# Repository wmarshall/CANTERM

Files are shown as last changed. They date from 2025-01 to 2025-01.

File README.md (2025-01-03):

# CANTERM

A single SKU for FRC teams providing the following features:

1. Fixed mounting junction for CAN connections, compatible with the 0.1" pitch connector of your choice (Molex SL footprints on silkscreen)
2. Solder pads and test points for 22AWG wire
3. 3 connection points - create short stubs out to individual devices and have a passthrough
4. Switchable termination - every junction can be a termination point!
5. Mountable to standard 0.5"x#10 FRC pitch grid

## Images

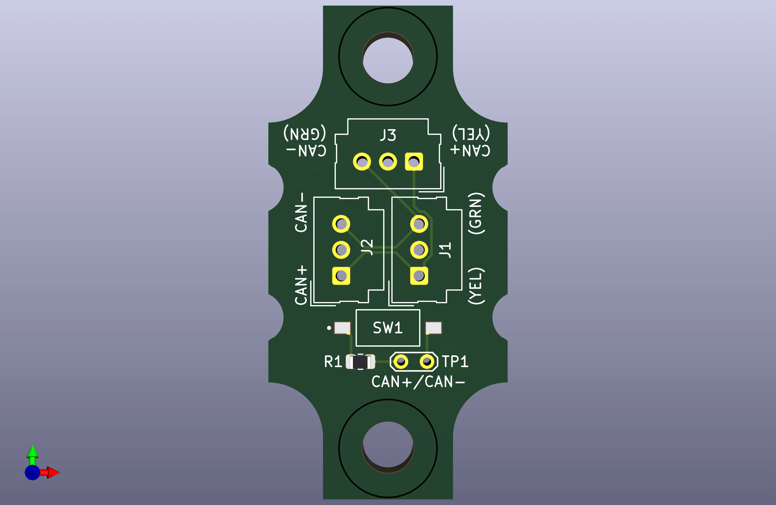
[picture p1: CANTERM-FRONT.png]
FRONT

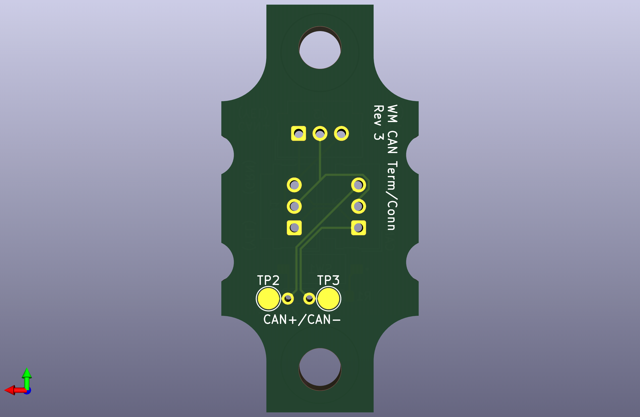
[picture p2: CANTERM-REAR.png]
REAR


Apologies for the flux slime + sharpied out silkscreen where I labeled things backwards in rev 1.

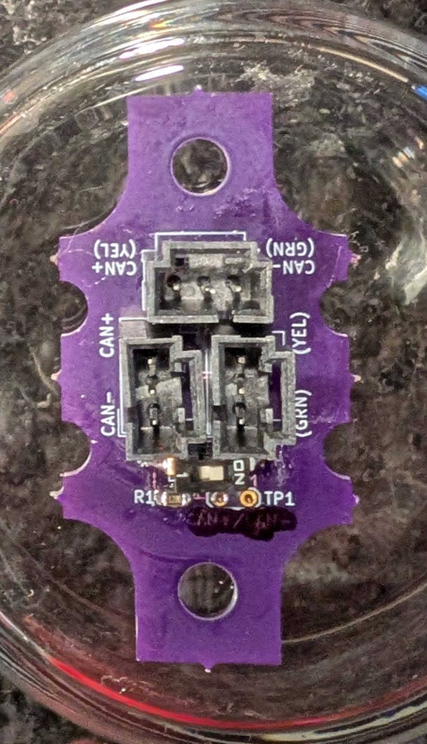
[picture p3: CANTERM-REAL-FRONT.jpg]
FRONT

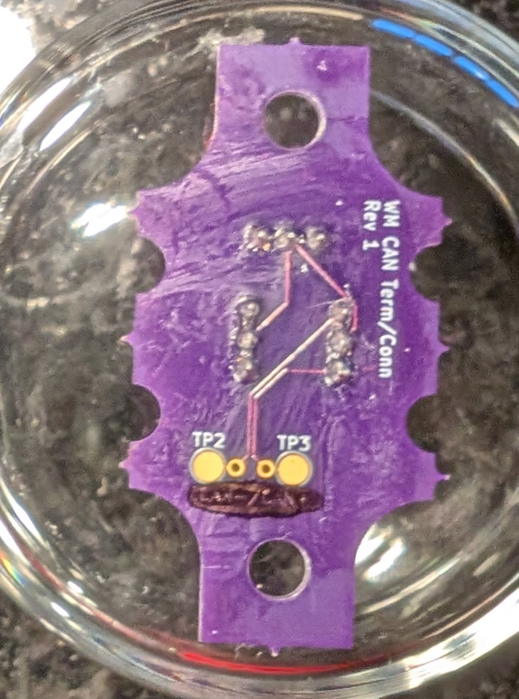
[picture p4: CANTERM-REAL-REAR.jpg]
REAR

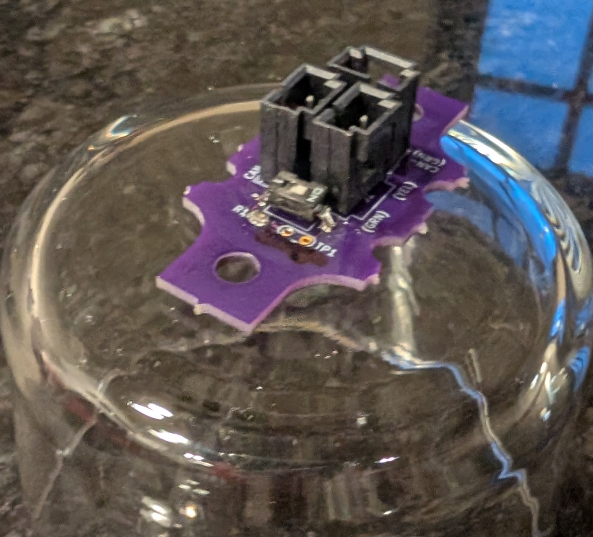
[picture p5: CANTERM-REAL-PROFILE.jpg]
PROFILE


## How to use

### Mounting

I recommend a fixed connection to a hard surface, with padding behind to prevent the through-hole pins from making electrical contact.

[Here](https://cad.onshape.com/documents/4bac7b549ef6666940699ce5/w/56cf0a0da1905853099fed6a/e/bae3fd6128463807bfcfc51d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) is a WIP Case CAD that accomplishes this.

### As a junction

1. Connect your input connector to one set of contacts
2. Connect your output connector to a second set of contacts
3. Set the termination switch to `OFF` (away from `ON`)

#### Debugging

Have a break in your CAN chain but don't know where it is? Use the switchable termination feature to find out where

1. Disconnect your output connector
2. Set the termination switch to `ON`
3. You should now have a properly terminated network on the input side. If problems persist, the break is on that side. If they don't the break is on the output side.
4. Repeatedly bisect the network until the problem is found
5. Reconnect connectors and set the termination back to `OFF`

### As a terminator

1. Connect your input connector to one set of contacts
3. Set the termination switch to `ON`

### As a junction with a stub

1. Connect your input connector to one set of contacts
2. Connect your output connector to a second set of contacts
3. Connect your stub connector to the third set of contacts
3. Set the termination switch to `OFF` (away from `ON`)

### As a terminator (soldered)

1. Strip ~3/8" of each of your CAN wires.
2. Feed them through the test points
3. Solder to the contact patches on the back, making sure to also solder through the test points
4. Trim excess wire.
5. Set the termination switch to `ON`

## BOM

1. 3x `Molex_SL_171971-0003` (only 2 needed if not making stubs)
2. 1x 120 ohm 0805 SMT resistor
3. 1x SPST 0.1" pitch SMT DIP switch (DS04-254-2-01BK-SMT is what I used)

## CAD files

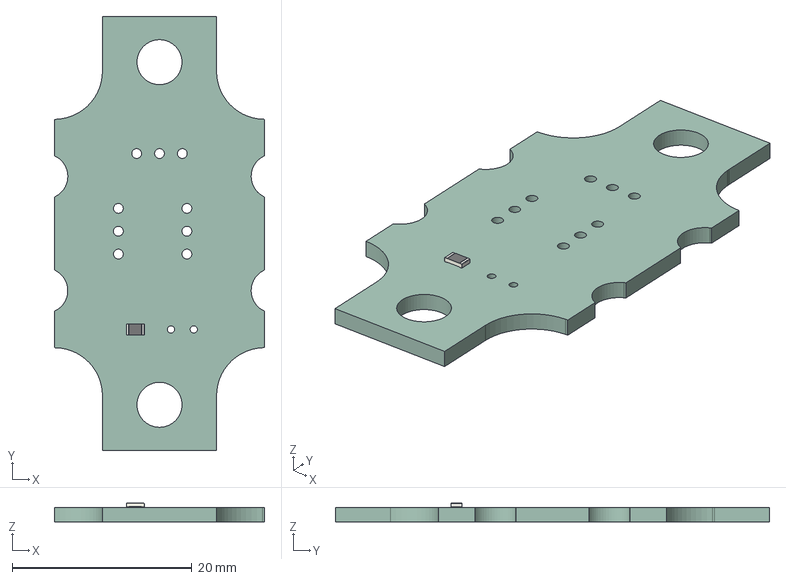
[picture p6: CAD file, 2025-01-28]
CANTERM.step
23.4 x 48.3 x 2.10 mm
R_0805_2012Metric
CANTERM_PCB

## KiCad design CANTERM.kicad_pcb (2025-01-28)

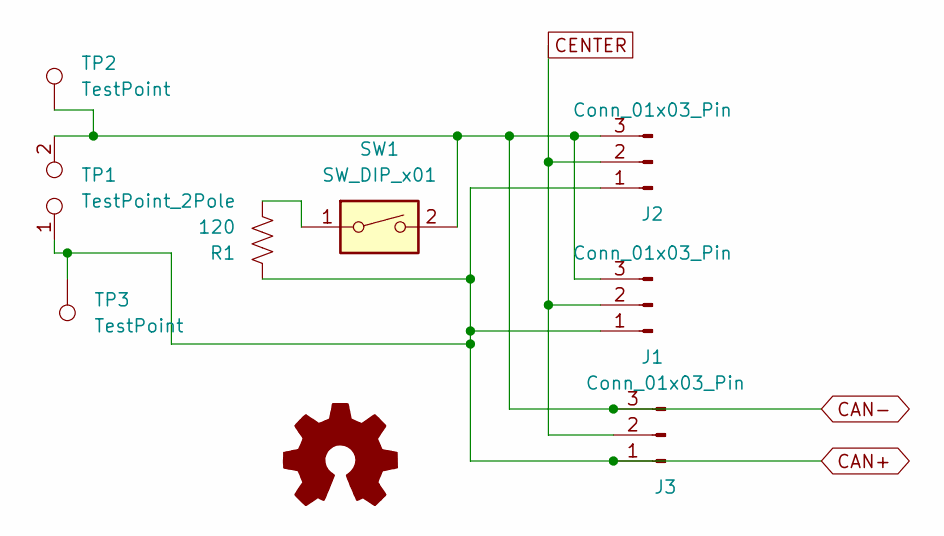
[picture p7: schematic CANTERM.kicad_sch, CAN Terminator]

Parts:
J1, J2, J3: Conn_01x03_Pin; Molex_SL_171971-0003_1x03_P2.54mm_Vertical
R1: 120; R_0805_2012Metric
SW1: SW_DIP_x01; SW_DS04-254-2-01BK-SMT
TP1: TestPoint_2Pole; TestPoint_2Pads_Pitch2.54mm_Drill0.8mm
TP2, TP3: TestPoint; TestPoint_Pad_D2.5mm

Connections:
CAN+: J1.1, J2.1, J3.1, R1.1, TP1.1, TP3.1
CAN-: J1.3, J2.3, J3.3, SW1.2, TP1.2, TP2.1
CENTER: J1.2, J2.2, J3.2
unnamed: R1.2, SW1.1

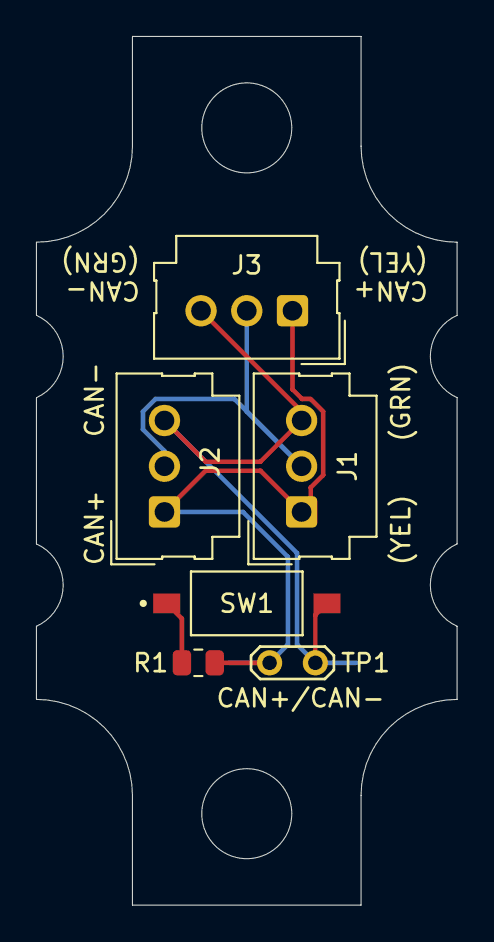
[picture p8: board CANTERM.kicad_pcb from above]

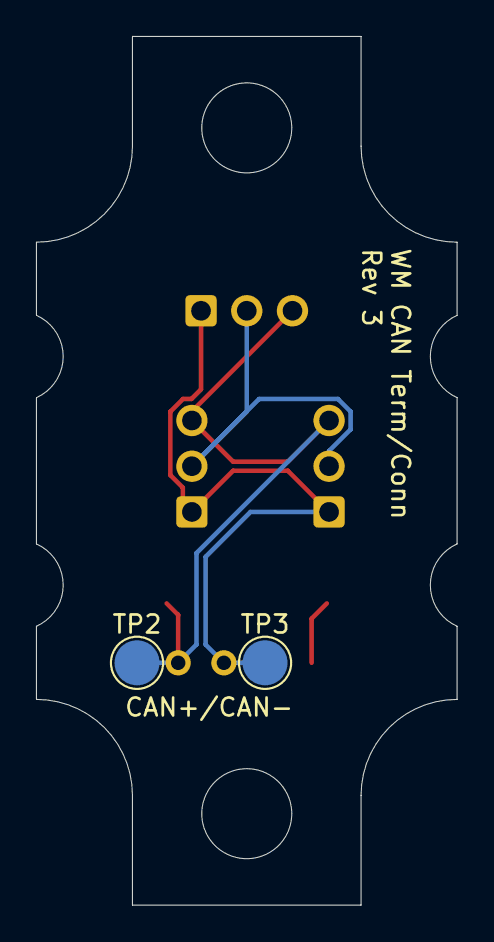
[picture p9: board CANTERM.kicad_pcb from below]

Board: 2 copper layers, 23.4 x 48.3 mm, 10 parts (2 on the bottom side), 4 nets.

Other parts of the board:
M1, M2: MountingHole_10

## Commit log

2024-12-10 3rd connector footprint for stub
    [CANTERM.kicad_pcb, CANTERM.kicad_sch]
2024-12-10 remove OSHW logo since I'm not compliant yet
    [CANTERM.kicad_pcb]
2025-01-03 wider tracks
    [CANTERM.kicad_pcb]
2025-01-03 initial release
    [CANTERM.kicad_pcb]
2025-01-23 slightly shrink board so it fits _inside_ the space envelope
    [CANTERM.kicad_pcb]
2025-01-23 add STEP
    [CANTERM.step]
2025-01-28 crying, correctly labeled pins
    [CANTERM.kicad_pcb, CANTERM.kicad_sch, CANTERM.step]
